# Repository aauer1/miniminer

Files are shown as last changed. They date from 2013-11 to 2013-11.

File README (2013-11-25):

MiniMiner One                            Copyright 2013 by Andreas Auer

It is a single Avalon ASIC Bitcoin miner powered by the USB port. I 
designed it as an initial project in the Bitcoin community.

Subdirectories:

- pcb:
  This is the schematic and layout file for the PCB. You have to use
  Cadsoft Eagle to open it.

- firmware:
  The firmware for the microcontroller is based on the LUFA USB stack
  for Atmel microcontrollers.
  To compile it, enter the LUFA-120730/Projects/AvalonBTC directory
  and type "make". You need the avr-gcc to compile it.

- bfgminer-driver:
  This directory includes the driver files for bfgminer. You have to 
  copy it to the bfgminer directory and modify the configure.ac file
  to get it compiled. 
  The driver is old and not compatible with an actual version of 
  bfgminer. It was developed with bfgminer 3.1.x. To run it on a newer
  version you have to modify it massively!

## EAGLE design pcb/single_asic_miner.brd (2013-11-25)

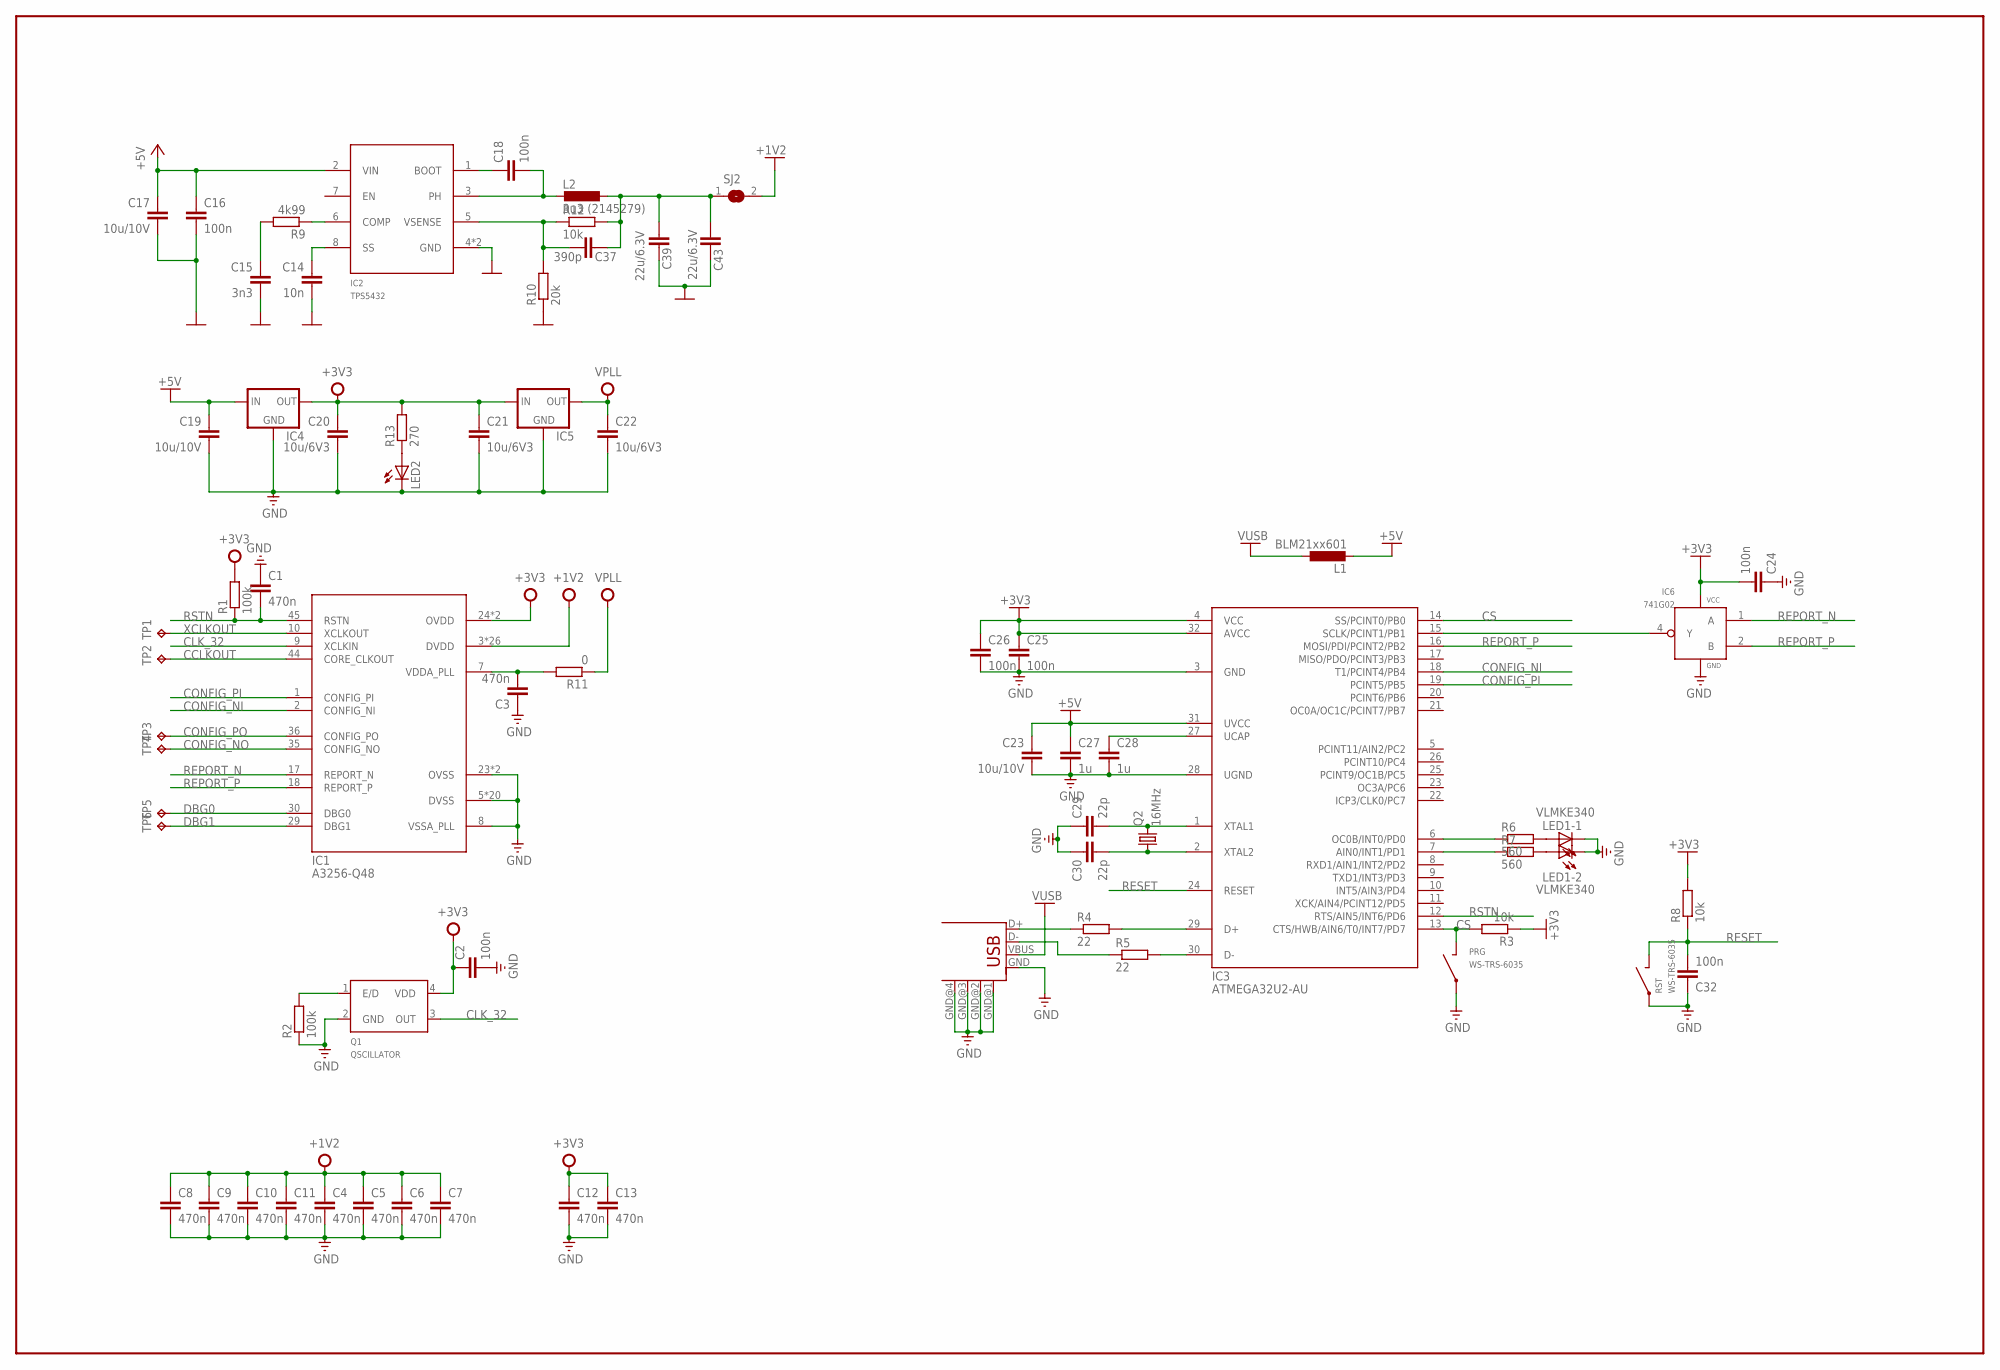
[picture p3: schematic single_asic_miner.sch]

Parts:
C1, C3, C4, C5, C6, C7, C8, C9, C10, C11, C12, C13: 470n; C0805
C2, C16, C18, C24, C25, C26, C32: 100n; C0805
C14: 10n; C0805
C15: 3n3; C0805
C17, C19, C23: 10u/10V; C0805
C20, C21, C22: 10u/6V3; C0805
C27, C28: 1u; C0805
C29, C30: 22p; C0805
C37: 390p; C0805
C39, C43: 22u/6.3V; C0805
IC1: A3256-Q48; QFN48
IC2: TPS5432; SO08E
IC3: ATMEGA32U2-AU; TQFP32
IC4, IC5: LM1117; SOT223
IC6: 741G02; SOT23-5
L1: BLM21xx601; L0805
L2: 3u3 (2145279); L4540
LED1: VLMKE340; PLCC4
LED2: LEDCHIP-LED0805; CHIP-LED0805
PRG: WS-TRS-6035; WS-TRS
Q1: QSCILLATOR; SMD7552
Q2: 16MHz; 6035
R1, R2: 100k; R0805
R3, R8, R12: 10k; R0805
R4, R5: 22; R0805
R6, R7: 560; R0805
R9: 4k99; R0805
R10: 20k; R0805
R11: 0; R0805
R13: 270; R0805
RST: WS-TRS-6035; WS-TRS
SJ2: SJ
TP1, TP2, TP3, TP4, TP5, TP6: TPB1,27; B1,27
X1: USB-SHIELD-1; USB-M-S1_1

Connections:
+1V2: C4.1, C5.1, C6.1, C7.1, C8.1, C9.1, C10.1, C11.1, IC1.3 (DVDD), IC1.4 (DVDD), IC1.6 (DVDD), IC1.11 (DVDD), IC1.12 (DVDD), IC1.13 (DVDD), IC1.14 (DVDD), IC1.15 (DVDD), IC1.16 (DVDD), IC1.19 (DVDD), IC1.21 (DVDD), IC1.22 (DVDD), IC1.25 (DVDD), IC1.26 (DVDD), IC1.27 (DVDD), IC1.28 (DVDD), IC1.31 (DVDD), IC1.33 (DVDD), IC1.34 (DVDD), IC1.39 (DVDD), IC1.40 (DVDD), IC1.41 (DVDD), IC1.43 (DVDD), IC1.46 (DVDD), IC1.47 (DVDD), IC1.48 (DVDD), SJ2.2
+3V3: C2.1, C12.1, C13.1, C20.1, C21.1, C24.2, C25.1, C26.1, IC1.24 (OVDD), IC1.37 (OVDD), IC3.4 (VCC), IC3.32 (AVCC), IC4.2 (OUT), IC5.3 (IN), IC6.5 (VCC), Q1.4 (VDD), R1.2, R3.1, R8.2, R13.2
+5V: C16.1, C17.1, C19.1, C23.1, C27.1, IC2.2 (VIN), IC3.31 (UVCC), IC4.3 (IN), L1.2
CCLKOUT: IC1.44 (CORE_CLKOUT), TP2.TP
CLK_32: IC1.9 (XCLKIN), Q1.3 (OUT)
CONFIG_NI: IC1.2 (CONFIG_NI), IC3.18 (T1/PCINT4/PB4)
CONFIG_NO: IC1.35 (CONFIG_NO), TP4.TP
CONFIG_PI: IC1.1 (CONFIG_PI), IC3.19 (PCINT5/PB5)
CONFIG_PO: IC1.36 (CONFIG_PO), TP3.TP
CS: IC3.13 (CTS/HWB/AIN6/T0/INT7/PD7), IC3.14 (SS/PCINT0/PB0), PRG.P$2, R3.2
D+: IC3.29 (D+), R4.2
D-: IC3.30 (D-), R5.2
DBG0: IC1.30 (DBG0), TP5.TP
DBG1: IC1.29 (DBG1), TP6.TP
GND: C1.1, C2.2, C3.1, C4.2, C5.2, C6.2, C7.2, C8.2, C9.2, C10.2, C11.2, C12.2, C13.2, C14.2, C15.2, C16.2, C17.2, C19.2, C20.2, C21.2, C22.2, C23.2, C24.1, C25.2, C26.2, C27.2, C28.2, C29.1, C30.1, C32.1, C39.2, C43.2, IC1.5 (DVSS), IC1.8 (VSSA_PLL), IC1.20 (DVSS), IC1.23 (OVSS), IC1.32 (DVSS), IC1.38 (OVSS), IC1.42 (DVSS), IC1.P$1 (DVSS), IC1.P$2 (DVSS), IC1.P$3 (DVSS), IC1.P$4 (DVSS), IC1.P$5 (DVSS), IC1.P$6 (DVSS), IC1.P$7 (DVSS), IC1.P$8 (DVSS), IC1.P$9 (DVSS), IC1.P$10 (DVSS), IC1.P$11 (DVSS), IC1.P$12 (DVSS), IC1.P$13 (DVSS), IC1.P$14 (DVSS), IC1.P$15 (DVSS), IC1.P$16 (DVSS), IC2.4 (GND), IC2.E (GND), IC3.3 (GND), IC3.28 (UGND), IC4.1 (GND), IC5.1 (GND), IC6.3 (GND), LED1.C1 (C), LED1.C2 (C), LED2.C, PRG.P$1, Q1.2 (GND), R2.1, R10.1, RST.P$1, X1.GND, X1.GND@1 (GND), X1.GND@2 (GND), X1.GND@3 (GND), X1.GND@4 (GND)
unnamed: IC3.15 (SCLK/PCINT1/PB1), IC6.4 (Y)
unnamed: Q1.1 (E/D), R2.2
unnamed: IC3.6 (OC0B/INT0/PD0), R6.1
unnamed: IC3.7 (AIN0/INT1/PD1), R7.1
unnamed: LED1.A1 (A), R6.2
unnamed: LED1.A2 (A), R7.2
unnamed: C3.2, IC1.7 (VDDA_PLL), R11.2
unnamed: R4.1, X1.D+
unnamed: R5.1, X1.D-
unnamed: C28.1, IC3.27 (UCAP)
unnamed: LED2.A, R13.1
unnamed: C29.2, IC3.1 (XTAL1), Q2.P$2 (2)
unnamed: C30.2, IC3.2 (XTAL2), Q2.P$1 (1)
unnamed: C14.1, IC2.8 (SS)
unnamed: IC2.6 (COMP), R9.1
unnamed: C15.1, R9.2
unnamed: C18.1, IC2.1 (BOOT)
unnamed: C18.2, IC2.3 (PH), L2.P$2 (2)
unnamed: C37.1, C39.1, C43.1, L2.P$1 (1), R12.2, SJ2.1
unnamed: C37.2, IC2.5 (VSENSE), R10.2, R12.1
REPORT_N: IC1.17 (REPORT_N), IC6.1 (A)
REPORT_P: IC1.18 (REPORT_P), IC3.16 (MOSI/PDI/PCINT2/PB2), IC6.2 (B)
RESET: C32.2, IC3.24 (RESET), R8.1, RST.P$2
RSTN: C1.2, IC1.45 (RSTN), IC3.12 (RTS/AIN5/INT6/PD6), R1.1
VPLL: C22.1, IC5.2 (OUT), R11.1
VUSB: L1.1, X1.VBUS
XCLKOUT: IC1.10 (XCLKOUT), TP1.TP

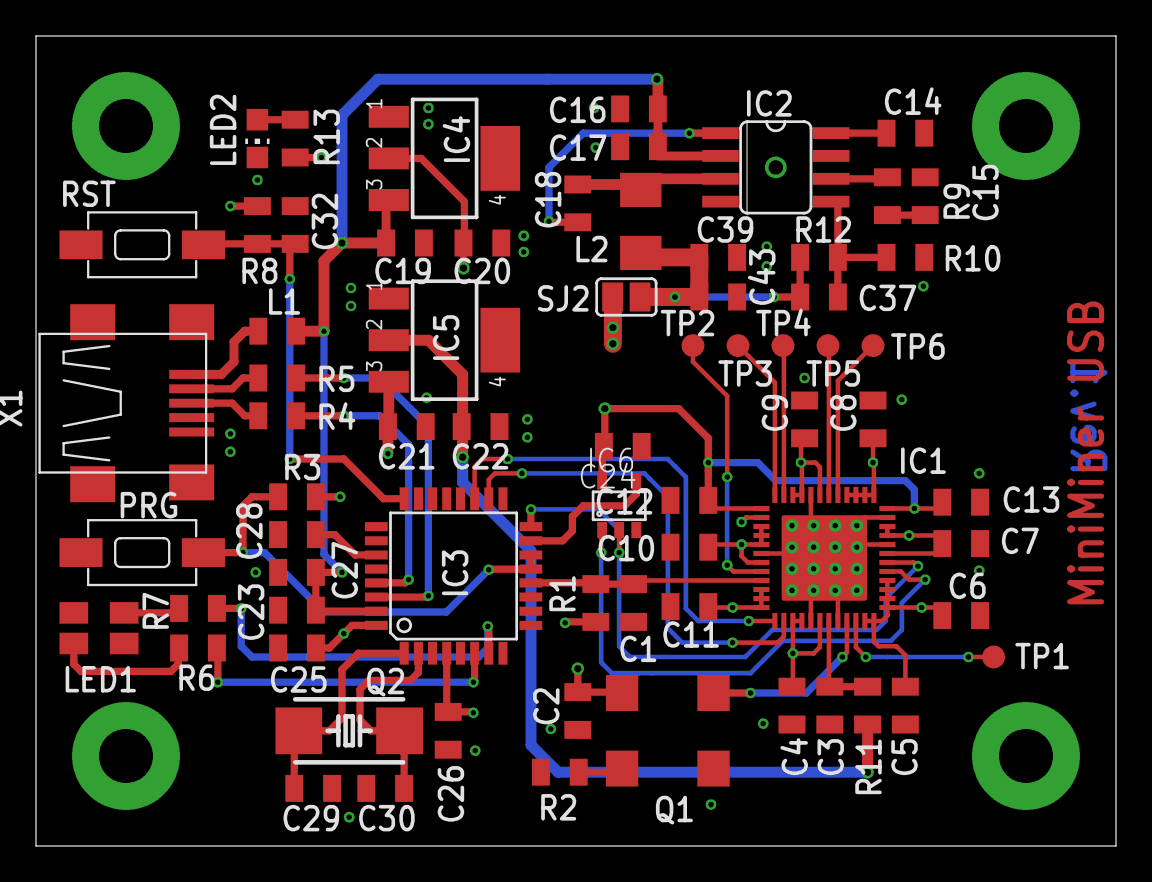
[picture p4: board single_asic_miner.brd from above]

Board: 4 copper layers, 60.0 x 45.0 mm, 69 parts (0 on the bottom side), 42 nets.

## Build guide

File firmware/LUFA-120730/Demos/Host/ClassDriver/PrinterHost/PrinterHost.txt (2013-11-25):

/** \file
 *
 *  This file contains special DoxyGen information for the generation of the main page and other special
 *  documentation pages. It is not a project source file.
 */

/** \mainpage Printer Host Demo
 *
 *  \section Sec_Compat Demo Compatibility:
 *
 *  The following list indicates what microcontrollers are compatible with this demo.
 *
 *  \li Series 7 USB AVRs (AT90USBxxx7)
 *
 *  \section Sec_Info USB Information:
 *
 *  The following table gives a rundown of the USB utilization of this demo.
 *
 *  <table>
 *   <tr>
 *    <td><b>USB Mode:</b></td>
 *    <td>Host</td>
 *   </tr>
 *   <tr>
 *    <td><b>USB Class:</b></td>
 *    <td>Printer Device</td>
 *   </tr>
 *   <tr>
 *    <td><b>USB Subclass:</b></td>
 *    <td>Bidirectional Protocol</td>
 *   </tr>
 *   <tr>
 *    <td><b>Relevant Standards:</b></td>
 *    <td>USBIF Printer Class Specification \n
 *        PCL Language Specification</td>
 *   </tr>
 *   <tr>
 *    <td><b>Supported USB Speeds:</b></td>
 *    <td>Low Speed Mode \n
 *        Full Speed Mode</td>
 *   </tr>
 *  </table>
 *
 *  \section Sec_Description Project Description:
 *
 *  Printer host demonstration application. This gives a simple reference
 *  application for implementing a USB Printer host, for USB printers using
 *  the bidirectional data encapsulation protocol and PCL language.
 *
 *  Upon connection of a compatible printer, the printer's device ID is sent
 *  to the AVR's serial port, and a simple test page is printed using the PCL
 *  printer language.
 *
 *  \section Sec_Options Project Options
 *
 *  The following defines can be found in this demo, which can control the demo behaviour when defined, or changed in value.
 *
 *  <table>
 *   <tr>
 *    <td>
 *     None
 *    </td>
 *   </tr>
 *  </table>
 */

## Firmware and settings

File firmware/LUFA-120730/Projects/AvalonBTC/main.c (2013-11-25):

/*
 LUFA Library
 Copyright (C) Dean Camera, 2012.

 dean [at] fourwalledcubicle [dot] com
 www.lufa-lib.org
 */

/*
 Copyright 2012  Dean Camera (dean [at] fourwalledcubicle [dot] com)

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
 The author disclaim all warranties with regard to this
 software, including all implied warranties of merchantability
 and fitness.  In no event shall the author be liable for any
 special, indirect or consequential damages or any damages
 whatsoever resulting from loss of use, data or profits, whether
 in an action of contract, negligence or other tortious action,
 arising out of or in connection with the use or performance of
 this software.
 */

/** \file
 *
 *  Main source file for the USBtoSerial project. This file contains the main tasks of
 *  the project and is responsible for the initial application hardware configuration.
 */

#include <stdio.h>

#include "main.h"
#include "clock.h"
#include "timer.h"

#include "application.h"

static void debug(char c, FILE *stream);
static FILE debug_stdout = FDEV_SETUP_STREAM(debug, NULL, _FDEV_SETUP_WRITE);

/** LUFA CDC Class driver interface configuration and state information. This structure is
 *  passed to all CDC Class driver functions, so that multiple instances of the same class
 *  within a device can be differentiated from one another.
 */
USB_ClassInfo_CDC_Device_t VirtualSerial_CDC_Interface =
{
    .Config =
    {
            .ControlInterfaceNumber = 0,
            .DataINEndpoint =
            {
                .Address = CDC_TX_EPADDR,
                .Size = CDC_TXRX_EPSIZE,
                .Banks = 1,
            },
            .DataOUTEndpoint =
            {
                .Address = CDC_RX_EPADDR,
                .Size = CDC_TXRX_EPSIZE,
                .Banks = 1,
            },
            .NotificationEndpoint =
            {
                .Address = CDC_NOTIFICATION_EPADDR,
                .Size = CDC_NOTIFICATION_EPSIZE,
                .Banks = 1,
            },
    },
};

static Application app =
{
    .cdc_info = &VirtualSerial_CDC_Interface,
};

//------------------------------------------------------------------------------
static void debug(char c, FILE *stream)
{
    if(c == '\n')
        RingBuffer_Insert(&app.USARTtoUSB_Buffer, '\r');
    RingBuffer_Insert(&app.USARTtoUSB_Buffer, c);
}

//------------------------------------------------------------------------------
int main(void)
{
    Timer timer;

    stdout = &debug_stdout;

    SetupHardware();

    appInit(&app);

    LEDs_SetAllLEDs(LEDMASK_USB_NOTREADY);

    timerSet(&timer, 10);
    sei();

    for(;;)
    {
        if(CDC_Device_BytesReceived(&VirtualSerial_CDC_Interface))
        {
            appUsbDataReceived(&app);
        }

        uint16_t BufferCount = RingBuffer_GetCount(&app.USARTtoUSB_Buffer);
        if(timerExpired(&timer) || (BufferCount > 0))
        {
            timerRestart(&timer);
            while(BufferCount--)
            {
                if(CDC_Device_SendByte(&VirtualSerial_CDC_Interface, RingBuffer_Peek(&app.USARTtoUSB_Buffer)) != ENDPOINT_READYWAIT_NoError)
                {
                    break;
                }

                RingBuffer_Remove(&app.USARTtoUSB_Buffer);
            }
        }

        appService(&app);
        CDC_Device_USBTask(&VirtualSerial_CDC_Interface);
        USB_USBTask();
    }
}

//------------------------------------------------------------------------------
/** Configures the board hardware and chip peripherals for the demo's functionality. */
void SetupHardware(void)
{
    MCUSR &= ~(1 << WDRF);
    wdt_disable();

    DDRB = 0x0C;
    PORTB = 0x0F;

    DDRD = 0x43;
    PORTD = 0x40;

    TCCR1A = _BV(COM1B0);
    OCR1B  = 0;
    TCCR1B = _BV(WGM12) | _BV(CS10);
    
    clock_prescale_set(clock_div_1);

    clockInit();

    LEDs_Init();
    USB_Init();
}

//------------------------------------------------------------------------------
/** Event handler for the library USB Connection event. */
void EVENT_USB_Device_Connect(void)
{
    LEDs_SetAllLEDs(LEDMASK_USB_ENUMERATING);
}

//------------------------------------------------------------------------------
/** Event handler for the library USB Disconnection event. */
void EVENT_USB_Device_Disconnect(void)
{
    LEDs_SetAllLEDs(LEDMASK_USB_NOTREADY);
}

//------------------------------------------------------------------------------
/** Event handler for the library USB Configuration Changed event. */
void EVENT_USB_Device_ConfigurationChanged(void)
{
    bool ConfigSuccess = true;

    ConfigSuccess &= CDC_Device_ConfigureEndpoints(&VirtualSerial_CDC_Interface);

    LEDs_SetAllLEDs(ConfigSuccess ? LEDMASK_USB_READY : LEDMASK_USB_ERROR);
}

//------------------------------------------------------------------------------
/** Event handler for the library USB Control Request reception event. */
void EVENT_USB_Device_ControlRequest(void)
{
    CDC_Device_ProcessControlRequest(&VirtualSerial_CDC_Interface);
}

//------------------------------------------------------------------------------
/** Event handler for the CDC Class driver Line Encoding Changed event.
 *
 *  \param[in] CDCInterfaceInfo  Pointer to the CDC class interface configuration structure being referenced
 */
void EVENT_CDC_Device_LineEncodingChanged(USB_ClassInfo_CDC_Device_t* const CDCInterfaceInfo)
{
#if 0
    uint8_t ConfigMask = 0;

    switch (CDCInterfaceInfo->State.LineEncoding.ParityType)
    {
            case CDC_PARITY_Odd:
                    ConfigMask = ((1 << UPM11) | (1 << UPM10));
                    break;
            case CDC_PARITY_Even:
                    ConfigMask = (1 << UPM11);
                    break;
    }

    if (CDCInterfaceInfo->State.LineEncoding.CharFormat == CDC_LINEENCODING_TwoStopBits)
        ConfigMask |= (1 << USBS1);

    switch (CDCInterfaceInfo->State.LineEncoding.DataBits)
    {
        case 6:
            ConfigMask |= (1 << UCSZ10);
            break;
        case 7:
            ConfigMask |= (1 << UCSZ11);
            break;
        case 8:
            ConfigMask |= ((1 << UCSZ11) | (1 << UCSZ10));
            break;
    }

    /* Must turn off USART before reconfiguring it, otherwise incorrect operation may occur */
    UCSR1B = 0;
    UCSR1A = 0;
    UCSR1C = 0;

    /* Set the new baud rate before configuring the USART */
    UBRR1  = SERIAL_2X_UBBRVAL(CDCInterfaceInfo->State.LineEncoding.BaudRateBPS);

    /* Reconfigure the USART in double speed mode for a wider baud rate range at the expense of accuracy */
    UCSR1C = ConfigMask;
    UCSR1A = (1 << U2X1);
    UCSR1B = ((1 << RXCIE1) | (1 << TXEN1) | (1 << RXEN1));
#endif
}

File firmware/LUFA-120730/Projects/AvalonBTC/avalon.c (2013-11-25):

/*
 * avalon.c
 *
 *  Created on: 06.07.2013
 *      Author: DI Andreas Auer
 */

#include <avr/io.h>
#include <avr/interrupt.h>
#include <util/delay.h>

#include "main.h"
#include "avalon.h"

static uint32_t report_ = 0;
static uint32_t report_valid_ = 0;
static uint8_t report_count_ = 0;

static uint16_t report_timeout = 0;

#define r(x)    ((x-n)&7)

//------------------------------------------------------------------------------
ISR(SPI_STC_vect)
{
    SPCR &= ~_BV(SPIE);
    report_ = SPDR;

    report_timeout = 0;
    report_count_ = 1;
    while(report_count_ != 4)
    {
        if(SPSR & _BV(SPIF))
        {
            report_ <<= 8;
            report_ |= SPDR;
            report_count_++;
            report_timeout = 0;
        }
        else
        {
            report_timeout++;
            if(report_timeout == 1000)
                break;
        }
    }

    report_valid_ = 1;
}

//------------------------------------------------------------------------------
static void send32(uint32_t word)
{
    uint8_t i;
    uint8_t bit;

    for(i=0; i<32; i++)
    {
        bit = word & 0x01;
        DATA_PORT &= ~(DATA_N | DATA_P);
        _delay_us(1);
        word >>= 1;
        if(bit)
        {
            DATA_PORT |= DATA_P;
        }
        else
        {
            DATA_PORT |= DATA_N;
        }
        _delay_us(1);
    }
}

//------------------------------------------------------------------------------
void asicInit(void)
{
    DDRB  = 0x38;
    PORTB = 0x30;

    DDRD  |= _BV(PD6);
    PORTD |= _BV(PD6);

    SPCR = _BV(SPIE) | _BV(SPE) | _BV(CPHA) | _BV(DORD);
}

//------------------------------------------------------------------------------
void asicResetSpi(void)
{
    report_count_ = 0;
    report_valid_ = 0;

    asicDisableSpi();
    _delay_us(5);
    asicEnableSpi();
    _delay_us(1);
}

//------------------------------------------------------------------------------
void asicStop(void)
{
    report_count_ = 0;
    report_valid_ = 0;

    RESET_PORT &= ~RESET_PIN;
}

//------------------------------------------------------------------------------
void asicReset(void)
{
    report_count_ = 0;
    report_valid_ = 0;

    RESET_PORT &= ~RESET_PIN;
    _delay_ms(1);
    RESET_PORT |=  RESET_PIN;
    _delay_ms(1);
}

//------------------------------------------------------------------------------
void asicSend(uint32_t *buffer, uint8_t size)
{
    uint8_t i=0;
    for(i=0; i<size; i++)
    {
        send32(buffer[i]);
    }
}

//------------------------------------------------------------------------------
uint8_t asicReportValid(void)
{
    return report_valid_;
}

//------------------------------------------------------------------------------
uint32_t asicGetNonce(void)
{
    report_count_ = 0;
    report_valid_ = 0;

    return report_;
}

//------------------------------------------------------------------------------
uint32_t rotate(uint32_t x, uint8_t y)
{
    return ((x<<y) | (x>>(32-y)));
}

//------------------------------------------------------------------------------
void asicPrecalc(uint32_t *midstate, uint32_t *data, uint32_t *precalc)
{
    const uint32_t K[3] = { 0x428a2f98, 0x71374491, 0xb5c0fbcf };
#if 0
    uint32_t m[8];
    uint8_t n;

    uint32_t S1, ch, t1, S0, maj, t2;

    uint32_t temp1;

    for(n = 0; n < 8; n++)
        m[n] = midstate[n];

    for(n = 0; n < 3; n++)
    {
        S1 = rotate(m[4], 26) ^ rotate(m[4], 21) ^ rotate(m[4], 7);
        ch = (m[4] & m[5]) ^ (~m[4] & m[6]);
        t1 = m[7] + S1 + ch + K[n] + data[n];
        S0 = rotate(m[0], 30) ^ rotate(m[0], 19) ^ rotate(m[0], 10);
        maj = (m[0] & m[1]) ^ (m[0] & m[2]) ^ (m[1] & m[2]);
        t2 = S0 + maj;

        m[7] = m[6];
        m[6] = m[5];
        m[5] = m[4];
        m[4] = m[3] + t1;
        m[3] = m[2];
        m[2] = m[1];
        m[1] = m[0];
        m[0] = t1 + t2;

        precalc[2-n] = m[0];
        precalc[5-n] = m[4];
    }
#else
    uint32_t x, y, z;
    uint32_t m[8];
    uint8_t n;

    for(n = 0; n < 8; n++)
        m[n] = midstate[n];

    for(n = 0; n < 3; n++)
    {
        x = m[5-n] ^ m[6-n];
        x = x & m[4-n];
        x = m[6-n] ^ x;
        x += K[n];
        x += data[n];
        x += m[7-n];
        y = rotate(m[4-n], 26);
        z = rotate(m[4-n], 21);
        z = y^z;
        y = rotate(m[4-n], 7);
        z = y^z;
        m[7-n] = z+x;
        m[3-n] = m[3-n] + m[7-n];
        x = rotate(m[r(0)], 30);
        y = rotate(m[r(0)], 19);
        y = y^x;
        x = rotate(m[r(0)], 10);
        y = x^y;
        x = m[r(0)] | m[r(1)];
        x = m[r(2)] & x;
        z = m[r(0)] & m[r(1)];
        x = x | z;
        m[7-n] += y + x;

        precalc[2-n] = m[7-n];
        precalc[5-n] = m[3-n];
    }
#endif
}
